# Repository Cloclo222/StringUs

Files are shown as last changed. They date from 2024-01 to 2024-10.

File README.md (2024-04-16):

# Projet de S4 - Génie Robotique
Bienvenue sur le GitHub de StringUS, le projet de quatrième session de l'équipe 2!
C'est un robot SCARA permettant de créer du "String art" à l'aide d'un 
algorithme qui décompose une image en une série de connections entre différents clous. 
Afin de pouvoir reproduire le projet, l'ensemble du processus est détaillé dans notre [WikiHow](https://github.com/Cloclo222/StringUs/wiki)!

Voici un apercu du projet final et des membres de l'équipe : (Lien youtube)  <div style="display:flex; justify-content:center;">
  
</div>

Membres de l'équipe :

Émile Aimez

Matisse d’Anjou Thériault

Guillaume Dostie

Xavier Lefebvre

Loïc Legault

Aryel Morin-Mercier

Félix Tremblay

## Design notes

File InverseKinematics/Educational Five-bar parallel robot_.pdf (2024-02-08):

# Educational Five-Bar Parallel Robot

Xavier Cano-Ferrer

Abstract- The present paper describes the design of an educational five-bar parallel robot based on the Teensy microcontroller. The small size of the robot and the simplicity of its components makes it suitable for its easy reproduction and programming.

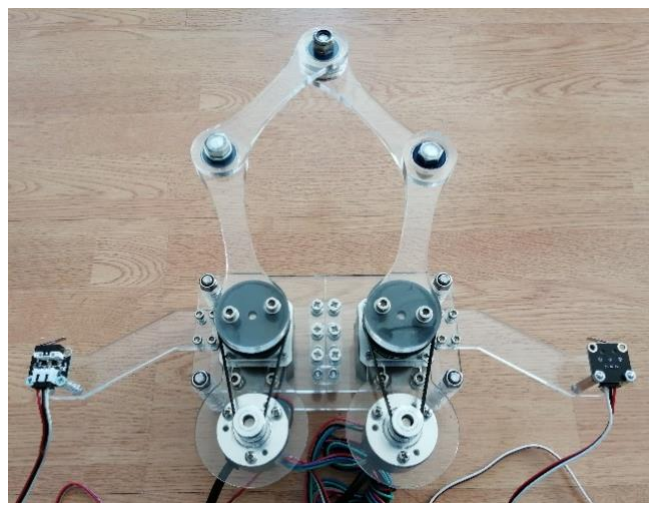
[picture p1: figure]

I. INTRODUCTION

Fiver-bar parallel robots have been studied in academia for years. Some of their most common applications are: drawing [1] [2] or engraving and manipulation [3] [4]. The presented desktop sized five-bar parallel robot (Figure 1) can be fully laser cut, manufactured in one day and programmed using the Arduino IDE and Teensyduino. For these reasons, it can be a good model to learn robotics concepts. The Robot actuators are two stepper motors Nema 17. The motors are driven by two A4988 Stepper Motor Driver Carrier, Black Edition [5]. A Teensy 3.2 microcontroller [6] is the programmable “brain” of the robot. Two limit switches [7] are located on the limits of the workspace of the robot and are used to perform the homing sequence of the robot. A PCB has been designed to operate the robot. All the dxf., step., stl. and Gerber files can be download from the Hackaday project’s page. The project started with a preliminary design based on two Pololu 37D 50:1 geared brushed DC motors sharing their shafts with two rotary incremental encoders. In this first design, the encoders were used to implement a PID position controller for each actuated joint. The control algorithm was programmed on an Arduino Mega 2650 and the motors were driven by the Pololu Dual MC33926 Motor Driver Arduino Shield. On the second design, the brushed DC motors were replaced by stepper motors and the third design is a hybrid of both. The robot is still designed to be operated with the teensyStep library but it has the incremental encoders coupled with the motor shafts to be able to record desired trajectories. All the information of the three designs can be found on the Hackaday project page [8]. In this article the third design will be treated.

II. FORWARD KINEMATICS

The forward kinematic equations have been adapted from Vathan et al. [9]. The equations can be used on the program of the robot to evaluate the position of the end effector of the robot for the given angles q1 and q2 (Figure 2).

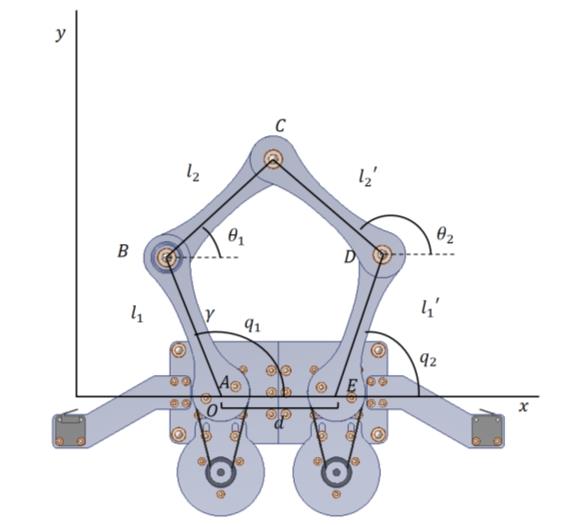
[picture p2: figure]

Figure 2: Forward kinematics diagram of the robot.

Figure 1: Five-bar parallel desktop robot manufactured and asembled.

The position of the end effector can be calculated using the equations:

xC = l1 cos q1 + l2 cos θ1 = d + l1

′
cos q2 + l2

′
cos θ2

yC = l1 sin q1 + l2 sin θ1 = l1

′
sin q2 + l2

′
sin θ2

The joints B and D are not actuated by the stepper motors. For that reason the angles θ1 and θ2 are dependant and q1 and q2 are independent:

θ1 = sin⁻¹ (
l2

′
sin θ2 += l1

′
sin q2 − l1 sin q1
l2

)

θ2 = 2 tan⁻¹ (

A ± √A² + B² − C
2
B − C

)

The value of A, B and C is found using the expressions:

A = 2l2

′
l1

′
sin q2 − 2l1l2

′
cos q1

B = 2l2

′
d − 2l1l2

′
cos q1 + 2l2

′
l1

′
cos q2

C = l1

2 − l2

2 + l1

′2
+ l2

′2
+ d

2
− l1l1

′
sin q1 sin q2
− 2l1d cos q1 + 2l1

′
d cos q2
− 2l1l1

′
cos q1 cos q2

III. INVERSE KINEMATICS

The inverse kinematics equations return the values of the angles q1 and q2 for each value [x,y] of the workspace of the robot (Figure 3). These two equations have been obtained using
geometric | methods. | The | robot | essential
dimensions to calculate the inverse kinematics can be summarized on figure 3. The inverse kinematics have been adapted from the RepRap blog of parallel SCARA 3D printer build [10] and on Shen et al. conference paper [11].

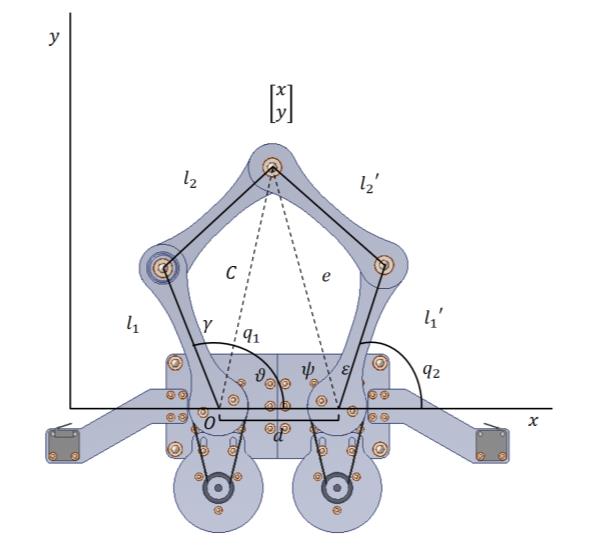
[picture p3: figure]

Figure 3: Inverse kinematics diagram of the robot.

l1 = l2 = l1

′ = l2

′ = 100 mm

d = 80 mm

Left side

C = √x
2 + y

2

θ = tan⁻¹ (

y
x

)

q1 = θ + γ

Applying the cosine rule:

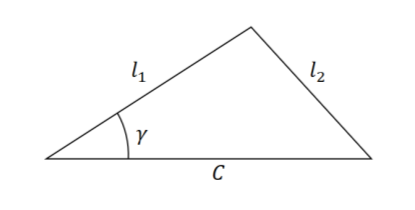
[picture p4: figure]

l2

2 = l1

2 + C
2 − 2l1C cos(γ)

γ = cos⁻¹ (
−l2

2 + l1

2 + C
2
2l1C

)

q1 = tan⁻¹ (

y
x

) + cos⁻¹ (
−l2

2 + l1

2 + C
2
2l1√x
2 + y

2

)

Right side

e = √(d − x)
2 + y

2

ψ = tan⁻¹ (

y
d − x

)

q2 = π − ε − ψ

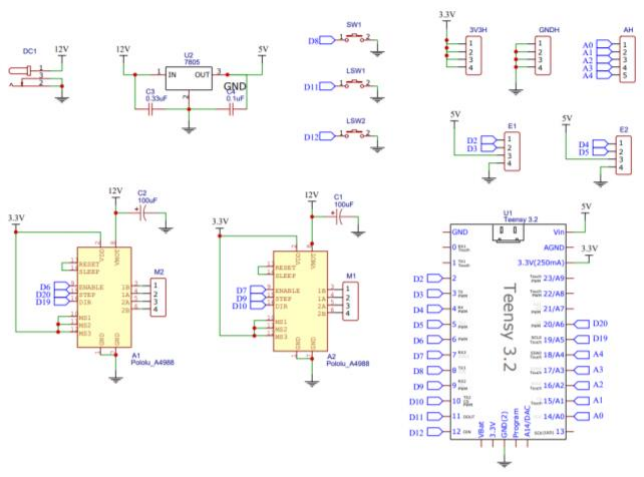
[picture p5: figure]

Applying the cosine rule again:

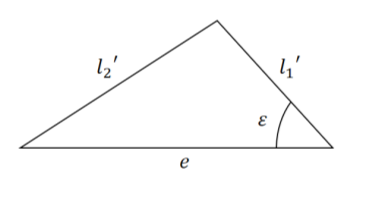
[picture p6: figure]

l2

′2
= l1

′2
+ e

2 − 2l1

′
e cos(ε)

ε = cos⁻¹ (
−l2

′2
+ l1

′2
+ e

2
2l1

′
e

)

q2 = π − tan⁻¹ (

y
d − x

) − cos⁻¹ (
−l2

′2
+ l1

′2
+ e

2

2l1

′√(d − x)
2 + y

2

)

The workspace of the robot can be configured using different modes. This has been studied and implemented on the DexTAR Robot [4] and Tien Dung et al. [12]. These modes are summarized as follows:

- Mode “+-”: q1 = θ + γ and q2 = π − ψ − ε
- Mode “-+”: q1 = θ − γ and q2 = π − ψ + ε
- Mode “--”: q1 = θ − γ and q2 = π − ψ − ε
- Mode “++”: q1 = θ + γ and q2 = π − ψ + ε

The robot program works with mode “+-” by default but this can be changed on the inverse kinematic functions in order to get the desired behaviour.

IV. ELECTRONICS

The two drivers have the three mode pins (M0, M1 and M2) pulled-up (connected to the Teensy 3.3V pin) so the robot works by default with the 3200 steps per revolution resolution. Two 100 µF capacitors are connected to the VMOT pins in order to protect the driver from spikes. The working voltage of the encoders is supplied by a LM7805 voltage regulator (Figure 4). The intention of the third switch is to have an input to tell the robot when you want to use the encoders to record a trajectory to reproduce it afterwards.

V. TIMING BELT DESIGN

The number of teeth zp of the big and the small pulley have been adjusted to get a gear ratio of 3:1 where the number of pulses per revolution of the encoder is increased in a factor of three. In the case of the selected encoders, from 600 pulses/revolution to 1800 pulses per revolution. Due to the dimensions of the robot, the adequate size of the timing belt is the GT2. Therefore, the pitch is 2.032 mm.

dp =

p zp
π

Once the big and small pulley diameters defined (D and d) the distance between both C has been calculated in order to get the desired commercial length L:

L = 2C +

π
2

(D + d) +

(D − d)

2
4C

The length obtained is 192.95 mm and a commercial and suitable option is the: RS PRO, Timing Belt, 95 Teeth, 193.04 mm length and 6mm Width [13]. The encoders can be added as an additional feature because the encoder holder can be attached to the motor holder using two M4 screws. The belt tension can be adjusted by translating the encoder holder before tightening the screws.

Figure 4: Proposed schematic of the Robot including the two stepper motors, two limit switches, Pololu A4988, two encoder connections, one switch and the Teensy 3.2.

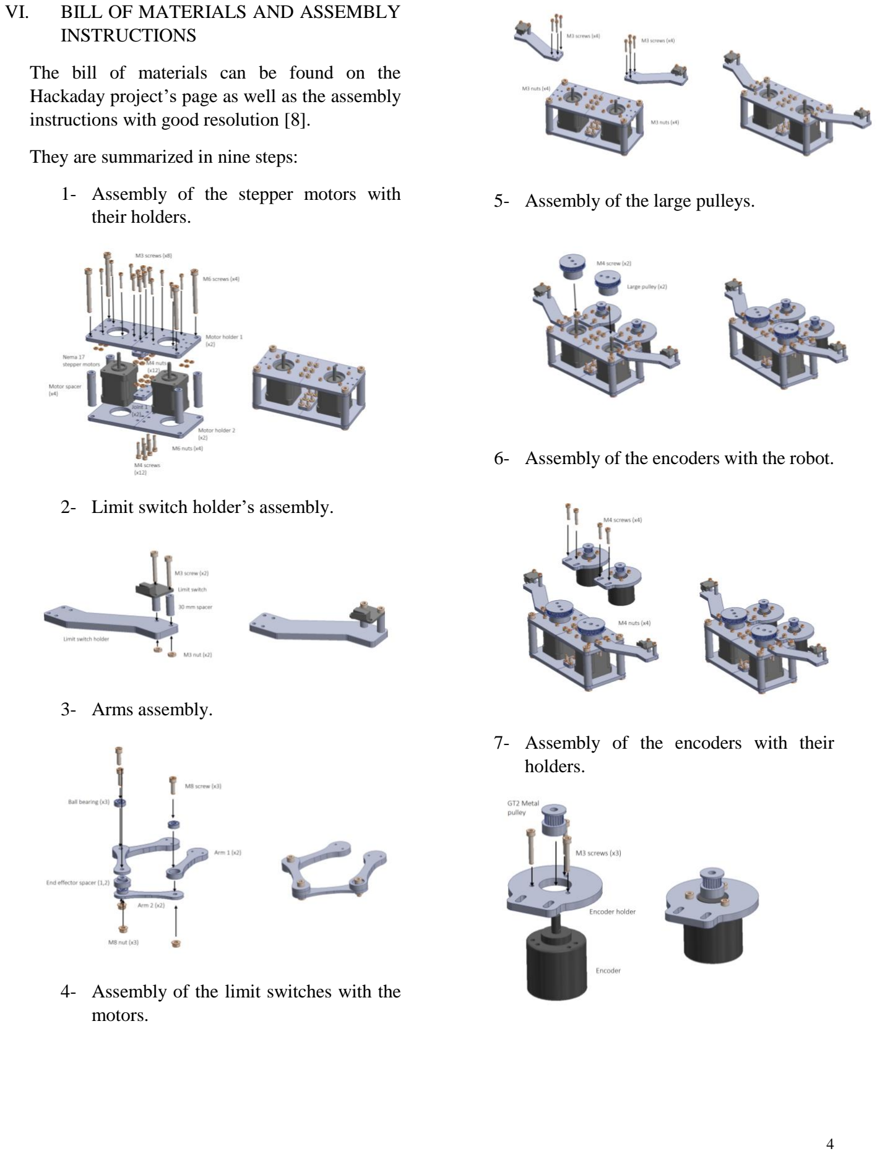
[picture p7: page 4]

VI. | BILL OF MATERIALS AND ASSEMBLY INSTRUCTIONS
| The bill of materials can be found on the Hackaday project’s page as well as the assembly instructions with good resolution [8].
| They are summarized in nine steps:
| 1- Assembly of the stepper motors with their holders.

2- Limit switch holder’s assembly.

3- Arms assembly.

4- Assembly of the limit switches with the motors.

5- Assembly of the large pulleys.

6- Assembly of the encoders with the robot.

7- Assembly of the encoders with their holders.

8- Timing belts assembly.

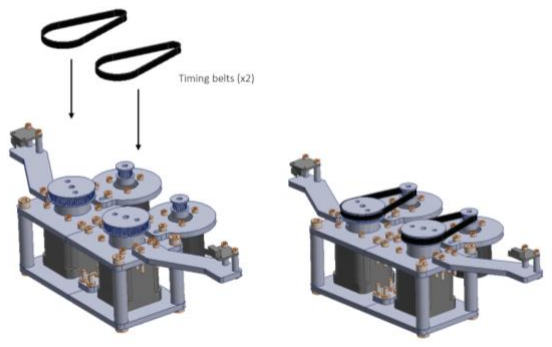
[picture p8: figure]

9- Assembly of the arms with the rest of the robot.

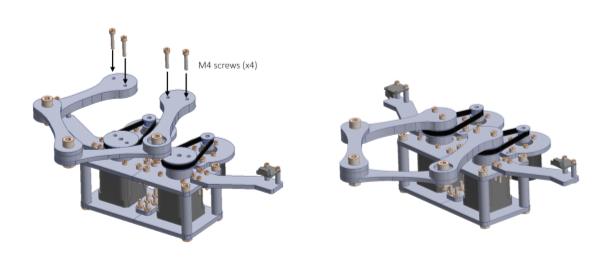
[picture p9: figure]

VI. BASIC PROGRAM

The robot is intended to use the TeensyStep library [14]. Which is perfect to manage several motors making a synchronous movement and also work with a huge range of speeds and accelerations (up to 300,000 steps/s and 500,000 steps/s^2) to get precise and fast movements to the robot. The homing procedure starts moving both arms to the right side until the right arm reaches the right end switch. Then the robot starts rotating both arms counter clock wise and counting the number of steps that the right arm is doing. When the left arm reaches the left end switch, both motors stop, the number of steps is converted to an angle and the left arm angle is set to 180 degrees. After the homing procedure, the end effector is moved on the position [40,170] and from that position is called to draw a small rectangle. A basic program of the robot drawing a square can be seen on YouTube [15].

VII. RESULTS

The Parallel robot has been designed to use the 3200 steps per revolution configuration. With this configuration, the theoretical resolution is 0.1125 degrees per step. The repeatability test has been measured in the x and y axes (N = 18, ω = 56.25 ° ∙ s

−1
and α = 112.5 ° ∙ s

−2
) using a
KATSU | Dial | Test | Indicator | [16]. | The
repeatability (RP) has been calculated using the equations proposed by Barrientos et al. where Lm and Ls are the average and the standard deviation of all the distances reached from the barycentre (Lj) [17]:

Lj = √(xj − xm)
| | | 2 + (yj − ym) | 2

Lm =

∑ Lj
n − 1

Ls = √
∑(Lj − Lm)
n − 1

RP = Lm + 3Ls

The repeatability (RP) obtained with the experimental results has been 0.1147 mm. This value corresponds to the cyan circle diameter (Figure 6).

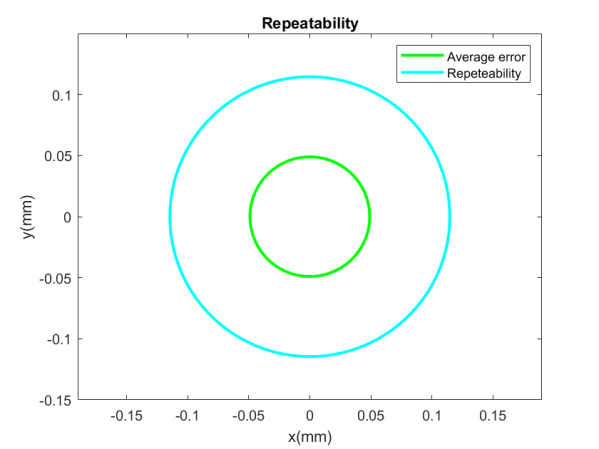
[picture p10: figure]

Figure 6: Repeatability and average error plot.

The repeatability test for the y axis can be seen on the YouTube channel [18].

VIII. DISCUSSION

This robot can be easily manufactured and assembled in a few hours. All the components are accessible and inexpensive.

The basic robot tools can be subject of study with this robot are: forward and inverse kinematics, homing sequence, stepper motor speed and acceleration profiles, closed loop position control algorithms (P, PI, PD, PID) and trajectory recording. For all this reasons this tool can be suitable to use in educational workshops for adults or practical lessons in engineering schools.

REFERENCES

[1] “https://www.thingiverse.com/thing:2480 09,” [Online].
[2] F. Cemal and I. Katip, “Real time controlled two dof five bar robot manipulator,” in Proceedings of the International Symposium of Mechanism and Machine Science, Baku, 2017.
[3] N. Siltala, A. Vuola, R. Heikkilä and R. Tuokko, “A H-scara mini robot - a dual parallel kinematics mini manipulator,” in Proceedings of the joint conference of the 41st International Symposium on Robotics, Munich, 2010.
[4] L. Campos, F. Bourbonnais, I. A. Bonev and P. Bigras , “DEVELOPMENT OF A FIVE-BAR PARALLEL ROBOT WITH LARGE WORKSPACE,” in Proceedings of the ASME 2010 International Design Engineering Technical Conferences & Computers and Information in Engineering Conference, Montreal, 2010.
[5] “https://www.pololu.com/product/2128,” [Online].
[6] “https://www.pjrc.com/store/teensy32.ht ml,” [Online].
[7] “https://www.amazon.co.uk/gp/product/B07F342J8K/ref=ppx_yo_dt_b_asin_title_o03_s00?ie=UTF8&psc=1,” [Online].
[8] “https://hackaday.io/project/173325-educational-five-bar-parallel-robot-double-scara,” [Online].
[9] L. Vathan.B, H. Kumar and B. . I. John. H, “Kinematic Analysis of Five-Bar Mechanism in Industrial Robotics”.
[10] “https://reprap.org/forum/read.php?185,4 90216,,” [Online].
[11] S. Yanli, L. Yanli, W. Hongtao, H. Chunlong and W. Shuai , “Forward and Inverse Kinematics for a Novel Double Scara Robot,” in 2nd International Symposium on Resource Exploration and Environmental Science, 2018.
[12] L. Tien Dung, K. Hee-Jun and D. Quang Vinh , “A Method for Optimal Kinematic Design of Five-bar Planar Parallel Manipulators,” 2017.
[13] “https://uk.rs-online.com/web/p/timing-belts/7785054/,” [Online].
[14] “https://luni64.github.io/TeensyStep/,” [Online].
[15] “https://www.youtube.com/watch?v=c6j G3WN4W8Y,” [Online].
[16] “https://www.amazon.co.uk/KATSU-Indicator-0-10mm-Magnetic-Storage/dp/B088FX6P91,” [Online].
[17] A. Barrientos, L. F. Peñin, C. Balaguer and R. Aracil Santoja, Fundamentos de Robótica, Madrid: McGraw-Hill, 2007.
[18] “https://www.youtube.com/watch?v=BfiHG13mHDs&feature=youtu.be,” [Online].

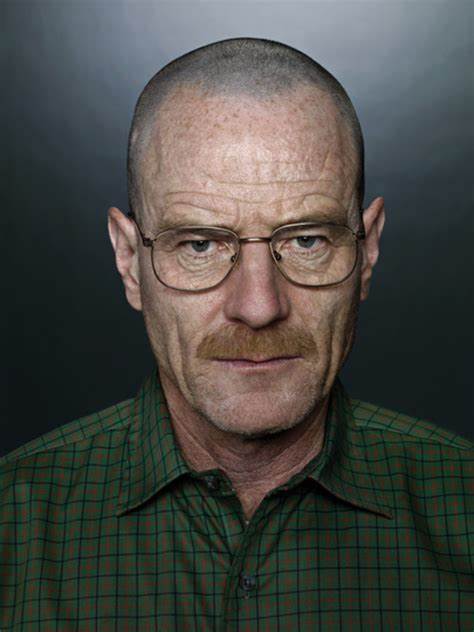
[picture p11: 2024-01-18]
[1] - ImageProcessing/imgs/waltuhIRL.jpg

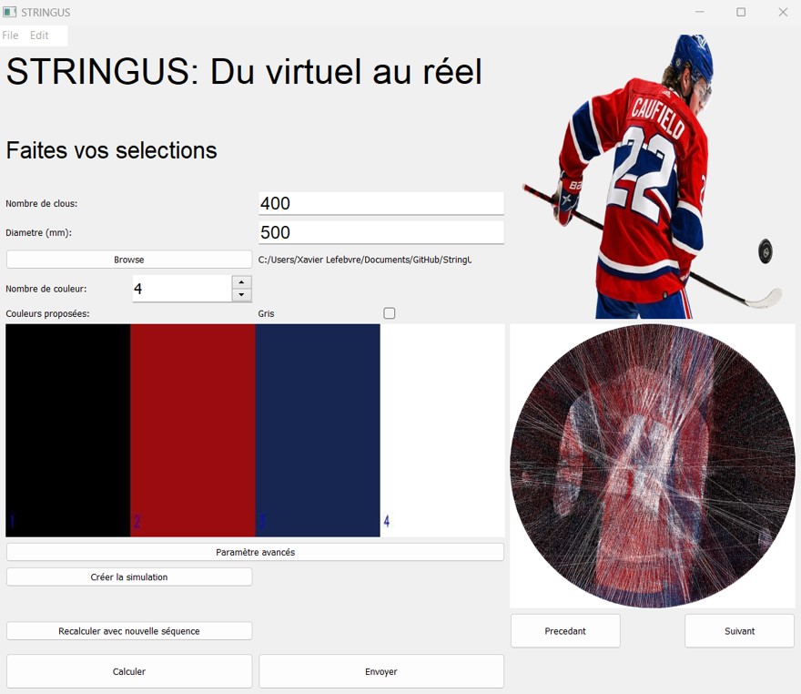
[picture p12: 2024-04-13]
Documents/Images/Main_window.jpg

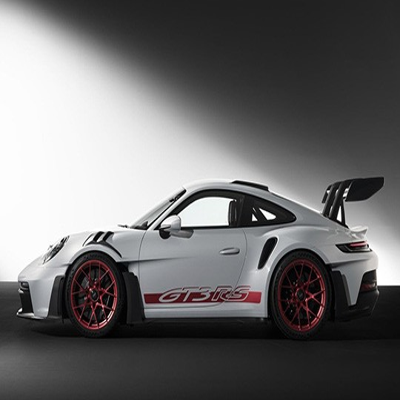
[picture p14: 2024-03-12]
[1] - ImageProcessing/imgs/porche.png

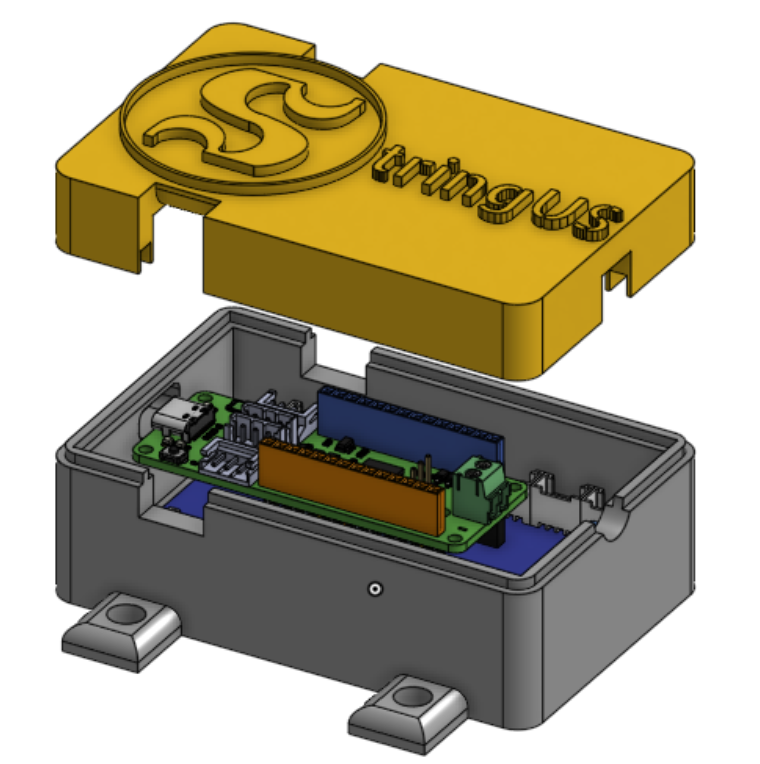
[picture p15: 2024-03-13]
Documents/Images/BoitierArduino.png

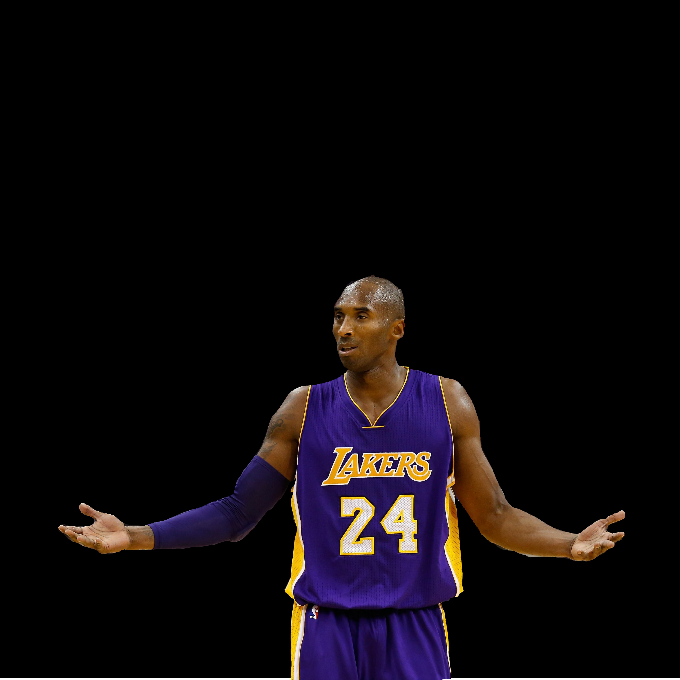
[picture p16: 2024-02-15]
[1] - ImageProcessing/imgs/the_rock.jpg

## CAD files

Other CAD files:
Documents/Materiel/Imprimante3D/SupportClouX5.sldprt
Documents/Materiel/Imprimante3D/LogoStringUS.sldprt
Documents/Materiel/Imprimante3D/PattesBaseX5.sldprt
Documents/Materiel/Imprimante3D/SupportBearingX3.sldprt

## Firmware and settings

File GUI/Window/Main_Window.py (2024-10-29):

import ast

# matplotlib.use("TkAgg")

from .PA_Window import *
from .Progress_Window import *
from .GetName_Window import *
from .Calibration_Window import *
from .Detection_Window import *


class Window(QWidget):
    def __init__(self):
        super().__init__()

        # Geometrie de la page
        self.setWindowTitle("STRINGUS")
        self.setGeometry(50, 50, 1, 1)

        # self.setStyleSheet("""
        #                    QWidget {
        #                        background-color: lightgrey;
        #                        color: green;
        #                    }
        #                    QLabel {
        #                        font-family: stylus;
        #                        color: Black;
        #                        border-radius: 50px;
        #
        #
        #                    }
        #                    QLabel#subtitle {
        #                        color: green;
        #                    }
        #                    QLabel#title {
        #                        color: green;
        #                    }
        #                    QLabel#side_label {
        #                        background-color: green;
        #                        color: yellow;
        #                        font-size: 30px;
        #                        font-weight: bold;
        #                        padding: 10px;
        #                        border-radius: 10px;
        #                        qproperty-alignment: 'AlignCenter';
        #                        margin-bottom: 10px;
        #                    }
        #                    QGroupBox {
        #                        border: 4px solid green;
        #                        border-radius: 15px;
        #                        margin-top: 20px;
        #                    }
        #                    QGroupBox::title {
        #                        subcontrol-origin: margin;
        #                        subcontrol-position: top left;
        #                        padding: 0 3px;
        #                        font-weight: bold;
        #                        color: green;
        #                    }
        #                    QLineEdit, QSpinBox, QCheckBox {
        #                        background-color: white;
        #                        color: green;
        #                        font-family: stylus;
        #                        border-radius: 10px;
        #                    }
        #                    QPushButton {
        #                        background-color: white;
        #                        color: black;
        #                        font-family: Stylus;
        #                        font-weight: bold;
        #                        font-size: 21px;
        #                        border-style: outset;
        #                        border-width: 2px;
        #                        border-radius: 10px;
        #                        border-color: black;
        #                    }
        #                    QPushButton:hover {
        #                        background-color: green;
        #                        color: gold;
        #                    }
        #                """)

        self.Titre = QLabel("STRINGUS: Du virtuel au réel")
        self.Titre.setObjectName("title")
        self.Titre.setFont(QFont('Arial', 30))

        self.sous_titre = QLabel("Faites vos selections")
        self.sous_titre.setFont(QFont('Arial', 20))

        # Creation du Menu
        self._createActions()
        self._createMenuBar()
        self._connectActions()

        # Variable Globale Necessaire
        self.fnameImage = 'Input/no.png'
        self.data_nbcouleur = 1
        self.rgb_values = []

        # Flags
        self.flag_calculate = False
        self.flag_browse = False
        self.flag_send = False
        self.flag_simulation = False
        self.flag_OpenCSV = False
        self.flag_sequenceCalculate = False

        # Parametre defaut
        self.GreyScale = False
        self.defautpoid = 10
        self.defautep = 10
        self.sequencedefaut = ""
        self.sequence()
        self.sizedef = "Real"
        self.nbclous = 150
        self.diam = 500
        self.compteur = 0
        self.TotalNumberLines = 0
        self.offset = 0
        self.portArduino = -1

        self.detect_openRB150()

        # Box Nombre de clous
        self.ClousLine = QLineEdit(str(self.nbclous))
        self.ClousLine.setValidator(QIntValidator())
        self.ClousLine.setMaxLength(4)
        self.ClousLine.setAlignment(Qt.AlignLeft)
        self.ClousLine.setFont(QFont("Arial", 15))

        # Box Diametre
        self.DimLine = QLineEdit(str(self.diam))
        self.DimLine.setValidator(QIntValidator())
        self.DimLine.setMaxLength(3)
        self.DimLine.setAlignment(Qt.AlignLeft)
        self.DimLine.setFont(QFont("Arial", 15))

        # Browse document
        BrowseButton = QPushButton("Browse")
        BrowseButton.clicked.connect(self.isBrowseButtonClick)
        self.image_path = QLabel("Vide")
        self.image_path.setMaximumWidth(299)

        # Calculate Button
        CalculateButton = QPushButton("Calculer")
        CalculateButton.clicked.connect(self.isCalculateButtonClick)
        CalculateButton.setMinimumHeight(50)

        # Envoie Button
        SendButton = QPushButton("Envoyer")
        SendButton.clicked.connect(self.isSendButtonClick)
        SendButton.setMinimumHeight(50)

        # Precedant Button
        PrecedantButton = QPushButton("Precedant")
        PrecedantButton.clicked.connect(self.isPrecedantButtonClick)
        PrecedantButton.setMinimumHeight(50)

        self.SimulationButton = QPushButton("Créer la simulation")
        self.SimulationButton.clicked.connect(self.isSimulationButtonClick)
        self.SimulationButton.setMinimumHeight(20)

        # Suivant Button
        NextButton = QPushButton("Suivant")
        NextButton.clicked.connect(self.isNextButtonClick)
        NextButton.setMinimumHeight(50)

        self.RecalculateSequenceButton = QPushButton("Recalculer avec nouvelle séquence")
        self.RecalculateSequenceButton.clicked.connect(self.isRecalculateSequenceButtonClick)
        self.RecalculateSequenceButton.setMinimumHeight(20)

        # Advanced Setting
        PAButton = QPushButton("Paramètre avancés")
        PAButton.clicked.connect(self.isPAButtonClick)

        # Nombre de couleur
        self.NbCouleurBox = QSpinBox(minimum=1, maximum=20, value=1)
        self.NbCouleurBox.valueChanged.connect(self.isNbCouleurChange)
        self.NbCouleurBox.setMinimumHeight(40)
        font = self.NbCouleurBox.font()
        font.setPointSize(12)
        self.NbCouleurBox.setFont(font)

        # Image a imprimer Stringus
        self.VOImage = QLabel()
        self.pixmap = QPixmap(self.resize_image(400, 400, self.fnameImage, 'Input/no.png'))
        self.VOImage.setPixmap(self.pixmap)

        # Image Couleur Dominante
        self.DominantImage = QLabel()
        self.pixmap = QPixmap(
            self.resize_image(700, 300, 'Input/grey.jpg', 'Input/grey.jpg'))
        self.DominantImage.setPixmap(self.pixmap)

        # Preview de l'oeuvre
        self.PreviewImage = QLabel()
        pixmap = QPixmap(
            self.resize_image(400, 400, 'Input/work.png', 'Input/work.png'))
        self.PreviewImage.setPixmap(pixmap)

        # Check Box grey
        self.GreyBox = QCheckBox()
        self.GreyBox.setGeometry(qtc.QRect(170, 120, 81, 20))
        self.GreyBox.stateChanged.connect(self.GreyBoxCheck)

        # Affichage
        layout = QGridLayout()

        # Add widgets to the layout
        layout.addWidget(self.Titre, 0, 0, 1, 4)
        layout.addWidget(self.sous_titre, 1, 0, 1, 3)
        # layout.setSpacing(0)
        layout.addWidget(QLabel("Nombre de clous:"), 2, 0, 1, 2)
        layout.addWidget(self.ClousLine, 2, 2, 1, 2)
        layout.addWidget(self.DimLine, 3, 2, 1, 2)
        layout.addWidget(QLabel("Diametre (mm):"), 3, 0, 1, 2)
        layout.addWidget(BrowseButton, 4, 0, 1, 2)

        layout.addWidget(self.image_path, 4, 2, 1, 2)

        layout.addWidget(QLabel("Nombre de couleur:"), 5, 0)
        layout.addWidget(self.NbCouleurBox, 5, 1)
        layout.addWidget(QLabel("Gris"), 6, 2)
        layout.addWidget(self.GreyBox, 6, 3)

        layout.addWidget(QLabel("Couleurs proposées:"), 6, 0, 1, 2)

        layout.addWidget(self.VOImage, 0, 4, 7, 5)
        layout.addWidget(self.DominantImage, 7, 0, 4, 4)

        layout.addWidget(PAButton, 11, 0, 1, 4)

        layout.addWidget(self.SimulationButton, 12, 0, 1, 2)

        layout.addWidget(self.RecalculateSequenceButton, 14, 0, 1, 2)

        layout.addWidget(CalculateButton, 15, 0, 1, 2)
        layout.addWidget(SendButton, 15, 2, 1, 2)
        layout.addWidget(self.PreviewImage, 7, 4, 7, 5)
        layout.addWidget(PrecedantButton, 14, 4, 1, 2)
        layout.addWidget(NextButton, 14, 7, 1, 2)

        self.RecalculateSequenceButton.setHidden(True)
        self.SimulationButton.setHidden(True)
        # Set the layout on the application's window
        self.setLayout(layout)

    def isSimulationButtonClick(self):
        self.flag_simulation = True
        self.canvas.animate(fps=60)
        QMessageBox.information(self, 'Simulation',
                                "La simulation est prête et elle se trouve maintenant dans vos dossiers",
                                QMessageBox.Ok)

    def isBrowseButtonClick(self):

        self.flag_browse = True
        self.flag_calculate = False
        self.flag_simulation = False

        self.transit = QFileDialog.getOpenFileName(self, 'Open file')
        self.fnameImage = self.transit[0]
        #
        # if not self.fnameImage:
        #     return
        if self.fnameImage:
            self.image_path.setText(self.fnameImage)
            self.pixmap = QPixmap(self.resize_image(400, 400, self.fnameImage, "Output/resize_image.png"))
            self.VOImage.setPixmap(self.pixmap)

            self.analyse_image(self.fnameImage)

            if self.GreyScale:
                self.pixmap = QPixmap(
                    self.resize_image(700, 300, 'Input/grey.jpg', 'Input/grey.jpg'))
                self.DominantImage.setPixmap(self.pixmap)
            else:
                self.pixmap = QPixmap(
                    self.resize_image(700, 300, 'Input/bar.jpg', 'Input/bar.jpg'))
                self.DominantImage.setPixmap(self.pixmap)
            self.flag_browse = False

            self.RecalculateSequenceButton.setHidden(True)
            self.SimulationButton.setHidden(True)

    def isRecalculateSequenceButtonClick(self):

        self.canvas.group_orders = self.sequencedefaut
        self.canvas.OrderColours()
        output = self.canvas.paintCanvas()
        output.save('Output/c0.png')
        WriteThreadedCsvFile("Output/ThreadedCSVFile.csv", self.canvas.totalLines)

        pixmap = QPixmap(
            self.resize_image(400, 400, 'Output/c0.png', 'Output/c0.png'))
        self.PreviewImage.setPixmap(pixmap)

        self.TotalNumberLines = self.canvas.getNumLines()

    def isCalculateButtonClick(self):

        self.nbclous = int(self.ClousLine.text())
        data_dim = int(self.DimLine.text())

        if not self.nbclous or not data_dim or self.fnameImage[0] == 'Input/no.png':
            QMessageBox.information(self, 'ERREUR', "Information manquante", QMessageBox.Ok)
            self.flag_calculate = False

        else:
            self.flag_calculate = True

            Radius = int(self.diam * 2)
            if self.GreyScale is False:

                palette = {}
                keys = range(self.data_nbcouleur)
                values = self.rgb_values
                for i in keys:
                    palette["c%i" % (i + 1)] = values[i]

                args = dict(
                    filename=self.fnameImage,
                    palette=palette,
                    group_orders=self.sequencedefaut,
                    img_radius=Radius,
                    numPins=self.nbclous,
                    lineWidth=self.defautep,
                    lineWeight=self.defautpoid
                )
                self.canvas = Canvas(**args)
                self.canvas.buildCanvas()
                output = self.canvas.paintCanvas()
                output.save('Output/c0.png')
                WriteThreadedCsvFile("Output/ThreadedCSVFile.csv", self.canvas.totalLines)
                for keys in self.canvas.img_couleur_sep.keys():
                    im = Image.fromarray(np.uint8(self.canvas.img_couleur_sep[keys]))
                    im.save("Output/%s.png" % keys)


            else:

                args = dict(
                    filename=self.fnameImage,
                    img_radius=Radius,
                    numPins=self.nbclous,
                    lineWidth=self.defautep,
                    lineWeight=self.defautpoid
                )
                self.canvas = Canvas(**args)
                self.canvas.buildCanvas()
                output = self.canvas.paintCanvas()
                output.save('Output/c0.png')
                WriteThreadedCsvFile("Output/ThreadedCSVFile.csv", self.canvas.totalLines)
                for keys in self.canvas.img_couleur_sep.keys():
                    im = Image.fromarray(np.uint8(self.canvas.img_couleur_sep[keys]))
                    im.save("Output/%s.png" % keys)

            pixmap = QPixmap(
                self.resize_image(400, 400, 'Output/c0.png', 'Output/c0.png'))
            self.PreviewImage.setPixmap(pixmap)

            self.TotalNumberLines = self.canvas.getNumLines()
            self.RecalculateSequenceButton.setHidden(False)
            self.SimulationButton.setHidden(False)

    def isSendButtonClick(self):

        if self.flag_calculate and self.portArduino != -1:

            if not self.flag_simulation:
                self.canvas.generateImgs()

            self.flag_send = True
            self.saveCSV("LastRunResume.csv")
            self.nbclous = int(self.ClousLine.text())
            self.ProgressBar = Window_Progress("Output/ThreadedCSVFile.csv", self.nbclous, self.TotalNumberLines,
                                               self.portArduino)
            self.ProgressBar.show()
            self.flag_send = False

            QMessageBox.information(self, 'ENVOYER',
                                    "Assurer vous d'avoir recalculer si vous avez changé des données depuis le dernier calcul",
                                    QMessageBox.Ok)

        elif self.portArduino == -1:
            QMessageBox.information(self, 'ERREUR', "Il n'y a pas d'Arduino de connecté", QMessageBox.Ok)

        else:
            QMessageBox.information(self, 'ERREUR', "Il faut calculer avant d'envoyer", QMessageBox.Ok)

    def isNextButtonClick(self):

        if self.GreyScale:
            return
        if self.flag_calculate:
            self.compteur += 1
            if self.compteur <= self.data_nbcouleur:
                name = "c" + str(self.compteur) + ".png"
                filename = "Output/" + name

            if self.compteur > self.data_nbcouleur:
                self.compteur = self.data_nbcouleur
                name = "c" + str(self.compteur) + ".png"
                filename = "Output/" + name

            pixmap = QPixmap(
                self.resize_image(400, 400, filename, filename))
            self.PreviewImage.setPixmap(pixmap)
        else:
            QMessageBox.information(self, 'ERREUR', "Il faut calculer avant", QMessageBox.Ok)

    def isPrecedantButtonClick(self):

        if self.GreyScale:
            return
        if self.flag_calculate:
            self.compteur -= 1
            if self.compteur >= 0:
                name = "c" + str(self.compteur) + ".png"
                filename = "Output/" + name

            if self.compteur < 0:
                self.compteur = 0
                name = "c" + str(self.compteur) + ".png"
                filename = "Output/" + name

            pixmap = QPixmap(
                self.resize_image(400, 400, filename, filename))
            self.PreviewImage.setPixmap(pixmap)
        else:
            QMessageBox.information(self, 'ERREUR', "Il faut calculer avant", QMessageBox.Ok)

    def isNbCouleurChange(self):

        self.RecalculateSequenceButton.setHidden(True)
        self.SimulationButton.setHidden(True)
        self.flag_calculate = False
        if not self.flag_OpenCSV:
            self.data_nbcouleur = self.NbCouleurBox.value()
            self.sequence()

            if self.fnameImage != 'Input/no.png':
                self.analyse_image(self.fnameImage)
                self.pixmap = QPixmap(
                    self.resize_image(700, 300, 'Input/bar.jpg', 'Input/bar.jpg'))
                self.DominantImage.setPixmap(self.pixmap)

    def isPAButtonClick(self):

        # Call fonction pour les parametres d'entree

        if self.rgb_values == []:
            QMessageBox.information(self, 'ERREUR', "Il n'y a pas d'image (;", QMessageBox.Ok)

        else:

            self.PM = Window_PA(self.data_nbcouleur, self.fnameImage, self.rgb_values, self.defautpoid,
                                self.defautep, self.sequencedefaut, self.sizedef, self.GreyScale)
            self.PM.submitted2.connect(self.UpdateValues)
            self.PM.show()

    def GreyBoxCheck(self):

        if self.GreyBox.checkState():
            self.GreyScale = True
            # print("here")
            self.pixmap = QPixmap(
                self.resize_image(700, 300, 'Input/grey.jpg', 'Input/grey.jpg'))
            self.DominantImage.setPixmap(self.pixmap)
            self.NbCouleurBox.setHidden(True)
        else:
            self.GreyScale = False
            self.NbCouleurBox.setHidden(False)
            if self.fnameImage != 'Input/no.png':
                self.analyse_image(self.fnameImage)
                self.pixmap = QPixmap(
                    self.resize_image(700, 300, 'Input/bar.jpg', 'Input/bar.jpg'))
                self.DominantImage.setPixmap(self.pixmap)

    def _createMenuBar(self):
        menuBar = QMenuBar(self)
        fileMenu = QMenu("&File", self)
        menuBar.addMenu(fileMenu)
        fileMenu.addAction(self.openAction)
        # fileMenu.addAction(self.LastRunResume)

        # Open Recent submenu
        self.openRecentMenu = fileMenu.addMenu("Open Recent")
        fileMenu.addAction(self.saveAction)

        fileMenu.addAction(self.LastRunResume)

        # fileMenu.addAction(self.Calibration)

        # Separator
        fileMenu.addSeparator()
        fileMenu.addAction(self.exitAction)
        # Edit menu
        # editMenu = menuBar.addMenu("&Edit")
        # editMenu.addAction(self.copyAction)
        # editMenu.addAction(self.pasteAction)
        # editMenu.addAction(self.cutAction)

        # Edit menu
        ToolsMenu = menuBar.addMenu("&Tools")
        ToolsMenu.addAction(self.CalibrationAction)
        ToolsMenu.addAction(self.PortAction)

    def _createActions(self):
        # File actions
        self.openAction = QAction(QIcon(":file-open.svg"), "&Open...", self)
        self.saveAction = QAction(QIcon(":file-save.svg"), "&Save", self)
        self.exitAction = QAction("&Exit", self)
        self.LastRunResume = QAction("&Last Run Resume", self)
        # self.Calibration = QAction("&Calibration", self)

        # String-based key sequences
        self.openAction.setShortcut("Ctrl+O")
        self.saveAction.setShortcut("Ctrl+S")
        self.LastRunResume.setShortcut("Ctrl+L")

        # Edit actions
        # self.copyAction = QAction(QIcon(":edit-copy.svg"), "&Copy", self)
        # self.pasteAction = QAction(QIcon(":edit-paste.svg"), "&Paste", self)
        # self.cutAction = QAction(QIcon(":edit-cut.svg"), "C&ut", self)
        # Standard key sequence
        # self.copyAction.setShortcut(QKeySequence.Copy)
        # self.pasteAction.setShortcut(QKeySequence.Paste)
        # self.cutAction.setShortcut(QKeySequence.Cut)

        self.CalibrationAction = QAction("&Calibration", self)
        self.PortAction = QAction("&Connection Port", self)

    def _connectActions(self):
        # Connect File actions
        self.openAction.triggered.connect(self.openFile)
        self.saveAction.triggered.connect(self.saveFile)
        self.exitAction.triggered.connect(self.close)
        self.LastRunResume.triggered.connect(self.last_run_resume)

        # Connect Edit actions
        # self.copyAction.triggered.connect(self.copyContent)
        # self.pasteAction.triggered.connect(self.pasteContent)
        # self.cutAction.triggered.connect(self.cutContent)

        # Slots
        self.CalibrationAction.triggered.connect(self.CalibrationIsTriggered)
        self.PortAction.triggered.connect(self.PortIsTriggered)

    def last_run_resume(self):
        self.flag_send = True
        self.openFile()
        self.nbclous = int(self.ClousLine.text())
        self.flag_send = False

        self.detect_openRB150()

        if self.portArduino == -1:
            QMessageBox.information(self, 'ERREUR', "Il n'y a pas d'Arduino de connecté", QMessageBox.Ok)
        else:
            self.ProgressBar = Window_Progress("Output/ThreadedCSVFile.csv", self.nbclous, self.TotalNumberLines,self.portArduino)
            self.ProgressBar.show()

    def CalibrationIsTriggered(self):
        if self.portArduino == -1:
            QMessageBox.information(self, 'ERREUR', "Il n'y a pas d'Arduino de connecté", QMessageBox.Ok)
        else:
            transit = "COM" + str(self.portArduino)
            self.Cal = Window_Calibration(self.portArduino)
            self.Cal.show()

    def PortIsTriggered(self):
        self.PO = Window_Detection(self.portArduino)
        self.PO.submitted3.connect(self.UpdateValuesPort)
        self.PO.show()

    def UpdateValuesPort(self, port):
        self.portArduino = port
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

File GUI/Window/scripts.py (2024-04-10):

# Importation des bibliothèques nécessaires
import numpy as np
import cv2
from scipy import ndimage
import math
from copy import deepcopy

# Définition de la classe Images pour le traitement d'images
class Images:
    def __init__(self, img):
        # Chargement de l'image depuis le fichier spécifié
        self.img = cv2.imread(img, 1)
        # Redimensionnement de l'image pour s'adapter à une taille prédéfinie
        if self.img.shape[0] / self.img.shape[1] < 0.76:
            self.img_width = 1100
            self.img_height = int(self.img_width * self.img.shape[0] / self.img.shape[1])
        else:
            self.img_height = 700
            self.img_width = int(self.img_height * self.img.shape[1] / self.img.shape[0])
        self.img = cv2.resize(self.img, (self.img_width, self.img_height))
        # Création d'une copie de l'image originale pour les opérations de réinitialisation
        self.img_copy = deepcopy(self.img)
        self.grand_img_copy = deepcopy(self.img)
        # Extraction du nom et du format de l'image à des fins de sauvegarde ultérieure
        self.img_name = img.split('\\')[-1].split(".")[0]
        self.img_format = img.split('\\')[-1].split(".")[1]
        # Initialisation des variables de recadrage
        self.left, self.right, self.top, self.bottom = None, None, None, None

    # Méthode pour ajuster automatiquement le contraste de l'image
    def auto_contrast(self):
        # Calcul de l'histogramme de l'image en niveaux de gris
        clip_hist_percent = 20
        gray = cv2.cvtColor(self.img, cv2.COLOR_BGR2GRAY)
        hist = cv2.calcHist([gray], [0], None, [256], [0, 256])
        hist_size = len(hist)
        accumulator = [float(hist[0])]
        for index in range(1, hist_size):
            accumulator.append(accumulator[index - 1] + float(hist[index]))
        maximum = accumulator[-1]
        clip_hist_percent *= (maximum / 100.0)
        clip_hist_percent /= 2.0
        minimum_gray = 0
        while accumulator[minimum_gray] < clip_hist_percent:
            minimum_gray += 1
        maximum_gray = hist_size - 1
        while accumulator[maximum_gray] >= (maximum - clip_hist_percent):
            maximum_gray -= 1
        # Calcul des paramètres d'ajustement du contraste
        alpha = 255 / (maximum_gray - minimum_gray)
        beta = -minimum_gray * alpha
        # Application de l'ajustement du contraste à l'image
        self.img = cv2.convertScaleAbs(self.img, alpha=alpha, beta=beta)

    # Autres méthodes pour les opérations de traitement d'images...
    # (auto_sharpen, auto_cartoon, auto_invert, change_b_c, change_saturation, remove_color, crop_img, rotate_img,
    # detect_face, bypass_censorship, save_img, reset, grand_reset)

# Fonction principale pour tester la classe Images
def main():
    # Chemin de l'image à charger
    path = "ppl.jpg"
    # Création d'une instance de la classe Images avec l'image spécifiée
    img = Images(path)
    # Extraction du nom de l'image
    img_name = path.split('\\')[-1].split(".")[0]
    # Affichage de l'image dans une fenêtre OpenCV
    cv2.imshow(img_name, img.img)
    cv2.waitKey()
    cv2.destroyAllWindows()

# Vérification si le script est exécuté en tant que programme principal
if __name__ == "__main__":
    # Appel de la fonction principale pour tester la classe Images
    main()

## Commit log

2024-01-17 CAFE BAILEYS. Ajouter la photo du pinout du board. Ajouter la librairie macros.h pour facilement débuguer le code. Créer un répertoire PlatformIO
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2024-01-18 Algorythme pour générer liste de clous, GREYSCALE ONLY, couleur est en cours.
    [threaded.csv]
2024-01-21 ÉTHANOL. Go 100% avec Arduino IDE, je suis pas capable de faire fonctionner VSCode.
    [threaded.csv]
2024-01-21 RHUM. La classe Scara.h fonctionne et initialise les moteurs, mais je ne suis pas capable de faire des Serial.println(). Il y a quelque chose qui buzz dans la communications UART
2024-01-21 HEINEKEN. La documentation est différente des sketch.ino. Ça existe pas Serial car il se fait overwrite, pour avoir accès au deuxième UART, faut utiliser Serial2. Serial1 est utiliser pour la communi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
2024-01-24 COUREURS DES BOIS. La classe est stable, capable de communiquer avec le Serial Monitor. Petits problèmes de communications avec les moteurs je crois, ils ont l'air de skip des instructions parfois
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2024-01-24 JÄGERNUKE - Séparation des images en n images de n couleur
    buss
    [threaded.csv, threaded_grey.csv]
2024-01-30 ABSOLUTE VODKA. Contrôle et limite des moteurs en place. Les moteurs se controllent maintenant en degrées.
2024-01-30 BARON SAMEDI. Limité la vitesse pour le homing() et capable d'être plus smooth.
2024-01-30 ON THE ROCK. On a essayer de modifier le sens des moteurs et leur homing_offset, mais quand déplugger, ça marche pas car ils font un tour complet.
2024-01-30 JACK & COKE. Faire homing_offset, ça marche pas car il doit quand même passer par le 0 absolue. On doit pas jouer avec ça
2024-02-06 GOLDSCHLÄGER - Restructuration complète
    Creation de class pour Image / Canvas
    [threaded_grey.csv]
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2024-02-07 Version correcte des settings servo
2024-02-07 CORONA LIME. On fait un carré!!! Les bras installé dessus sont good, avec des limites d'environ 90 à 125 deg.
2024-02-07 FINDUMONDE9%
    Ajout des fichiers de calcul / simulation MATLAB de la cinématique inverse d'un robot SCARA parallèle
2024-02-08 7TH HEAVEN - première image couleur yippie!!
    Canvas est maintenant une mega class.
    utilisation consist a créer une instance de canvas avec palette / paramètre désiré ( un "main" par image)
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2024-02-14 CHIC CHOC. Capable de communiquer de faire bouger les moteurs partir d'un script python par communication UART
2024-02-21 SOUR-DOUÉ. Rajouter une condition que la fonction setPos() n'est pas terminé seulement lorsque les moteurs sont à la bonne position
2024-02-21 VRAI LIQUOR CHARMS. Esti que ça marche mal Git quand tu sais pas quoi faire. Maudit Detached head
2024-02-24 JELLO SHOTS. Premier test de protocol pour la communication. Reste à enlever les erreurs.
2024-02-27 DUFF BEER. Rajouter fonction isPos() dans la classe Scara pour qu'il demande une autre commande quand il est à sa position. Dans la fonction, on peut modifier la marge d'erreur car getPresentPosition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
2024-03-02 ARCHIBALD - changed format of list of lines, fixed csv output, flipped lines
    lines is now a list of pins with the associated colour, allows better flexibility and clarity for csv output. can be easily converted to xy with Canvas.Coords[pin]
    or to Angles with np.linspace[0,2*pi,numPins],
    list of lines are now flipped so that first lines found are drawn last.
    [the_rock.csv]
2024-03-03 LABATT50
    Ajout de la fonction setSpeedForLinearMov(), qui permet de faire des déplacements linéaires. Ajuste les vitesses des moteurs indépendemment en fonction de leur différence d'angle à parcourir.
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2024-03-05 MIKES HARD LEMONADE - added cropping feature and fixed greyscale bug
    [shronk.csv, the_rock.csv]
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2024-03-06 BEACH DAY EVRY DAY VODKA
    Ajout du save d'un fichier de parametre V1
    [.csv, rrfr.csv]
2024-03-06 LIKES MARD HEMONADE - refixed greyscale for standardized csv output
    [shronk.csv]
2024-03-06 BEACH DAY EVERY DAY ICE
    Rajout de la partie des Parametres avances
    Bug avec le changement de couleur
    [thuuh.csv]
2024-03-07 PELOUSE - Updated CSV output to facilitate link between GUI and algorithm
    [shronk.csv, tigga.csv]
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2024-03-10 SIBOIRE
    - Finalisation PA
    - Ecriture CSV
    [.csv, rrfr.csv, thuuh.csv]
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2024-03-12 SIBOIRE Discipline
    Ajout Grey
    Changement Pah
    [fuck.csv, fuckloic.csv, jkjkj.csv]
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2024-03-12 COGNAC - Merge fonctionnel entre algorithme et GUI - reste a regarder le color picker
    [ThreadedCSVFile.csv]
2024-03-13 CHAMPAGNE - Version pls propre du GUI avec couleur fonctionnelle
    [ThreadedCSVFile.csv]
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2024-03-13 GRANDS-ÉCHEZAUX - Changement du gitignore, enregistrement des etapes de dither
    [ThreadedCSVFile.csv, fuck.csv, fuckloic.csv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]
2024-03-13 SIBOIRE SHERBIERE
    - Menage
    - Photo link avec algo
    [1.csv, 2.csv, 56688.csv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]
2024-03-13 SAKE - First sequence read from csv, dxl changed from UNIT_DEGREE to UNIT_RAW
    [ThreadedCSVFile.csv]
2024-03-15 BRANDY - added graph to track error of the motors
2024-03-19 SIBOIRE - PRESTA
    - Progress Bar
    - Correction certains bugs
    [2.csv, 56688.csv, LOL.csv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]
2024-03-19 SIBOIRE - TRIP D'AUTOMMNE
    Correct mineur de bug
    [ThreadedCSVFile.csv]
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2024-03-20 SIBOIRE BLEUALE
    - Fonction Crop
    [ThreadedCSVFile.csv]
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2024-03-21 SIBOIRE DISCIPLINE 2
    [ThreadedCSVFile.csv, dddd.csv, shronk.csv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]
2024-03-22 PAUSE BOTTON YIPPIE
    [ThreadedCSVFile.csv, test_com.csv]
2024-03-22 CHICKEN SOUP
    C5 working, GUI linked to arduino, GUI can resume progress even after loss of current
    wobbly table to adress
    [ThreadedCSVFile.csv, test_com.csv]
2024-03-25 Pink Whitney
    - Version Complete V1
    [ThreadedCSVFile.csv]
2024-03-26 LIQUORCHARMS
    Update des parametres de vitesses et acceleration des moteurs
    [ThreadedCSVFile.csv]
2024-03-27 Many Files
    [ThreadedCSVFile.csv]
2024-03-27 SHERBROUE
    Bug Open CSV
    [ThreadedCSVFile.csv]
2024-03-27 POLAR ICE - Ajout d'une animation pas encore implemente dans
    [ThreadedCSVFile.csv]
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2024-03-28 Fixed OpenFile bug
    [ThreadedCSVFile.csv]
2024-03-28 Latest tested version, fully working
    [ThreadedCSVFile.csv]
2024-03-28 GARFEELING - Updated progress window to show image of current strings + Last run resume dosen't reset progress bar %
    [ThreadedCSVFile.csv]
2024-03-28 minor tweaks to GUI behavior, added shortcut for LastRunResume and open shortcut automatically opens the parametre folder
    [ThreadedCSVFile.csv]
2024-03-30 Seperated OrderColours into own function to allow quick colour reordering without recalculating Lines
    [ThreadedCSVFile.csv]
2024-03-30 SMASH Limonade
    - Ajout des fonctions de tailles
    - Corrections de bugs mineurs
    - Redesign mineur du GUI
    - Nouveau type de CSV
    [ThreadedCSVFile.csv, dddd.csv, test_com.csv]
2024-03-30 SMASH Limonade 2
    - Ajout de fonctions
    [ThreadedCSVFile.csv]
2024-03-31 fixed bug ThreadedCSVFile would not reset when recalculating colour sequence
    [ThreadedCSVFile.csv]
2024-04-03 Beach Day Peche - Correction Bug Mineur
    [ThreadedCSVFile.csv]
2024-04-10 ALEXANDER KEITH - Ajouter des commentaires francais dans le code
    [ThreadedCSVFile.csv]
2024-04-10 DUVAL - Split Animation en deux et fix le probleme de folder non existant
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2024-07-23 Revert "Added functions to save scara calibration data to external AT24C256 E…"
2024-07-26 Simply Fraise
    [ThreadedCSVFile.csv]
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2024-07-27 Update Bug
    [ThreadedCSVFile.csv]
2024-08-02 Multiprocessing ComputeThreads()
    Added multiprocessing during Compute threads to slightly decrease computation time. time is still limited by largest (slowest) colour.
    Fixed bug which displayed inverted colours when opening preset files.
    [ThreadedCSVFile.csv]
2024-08-03 best line behaviour tweaked
    Best line was allocated to line with largest total darkness, now largest darkness per unit length.
    dosn't penalise short lines and dosn't reward long lines.
    [ThreadedCSVFile.csv]
2024-08-03 gitignore now working now functional, removed most input/outputs irrelevant to the code
    [ThreadedCSVFile.csv, shronk.csv, the_rock.csv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]
2024-08-10 Fixed COM port overwritting bug, Changed toggleTorque() behaviour
    Calibration window and send window would overwrite COM port value which sometimes caused bugs when user wishes to manually enter COM port for the openRB
    added functions TorqueOn and TorqueOff to explicitly turn torque on or off and toggleTorque() now takes no parameters and reads TORQUE_ENABLE value in _dxl control table to apply the opposite.
    [Calibration_Window.py, Detection_Window.py, Main_Window.py]
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2024-08-31 Fixed enable torque button autoactivation
    [Calibration_Window.py]
2024-08-31 Fixed auto detection language related bug
    [Calibration_Window.py, Detection_Window.py, Main_Window.py]
2024-08-31 fixed crash on next and prev buttons
    [Main_Window.py]
2024-08-31 Fixed GUI calibraion behavior bug
    [Calibration_Window.py]
2024-09-14 Fixed multiprocessing for exe, Cancel button on file dialogue, crop button
    [Calibration_Window.py, Main_Window.py, PA_Window.py]
